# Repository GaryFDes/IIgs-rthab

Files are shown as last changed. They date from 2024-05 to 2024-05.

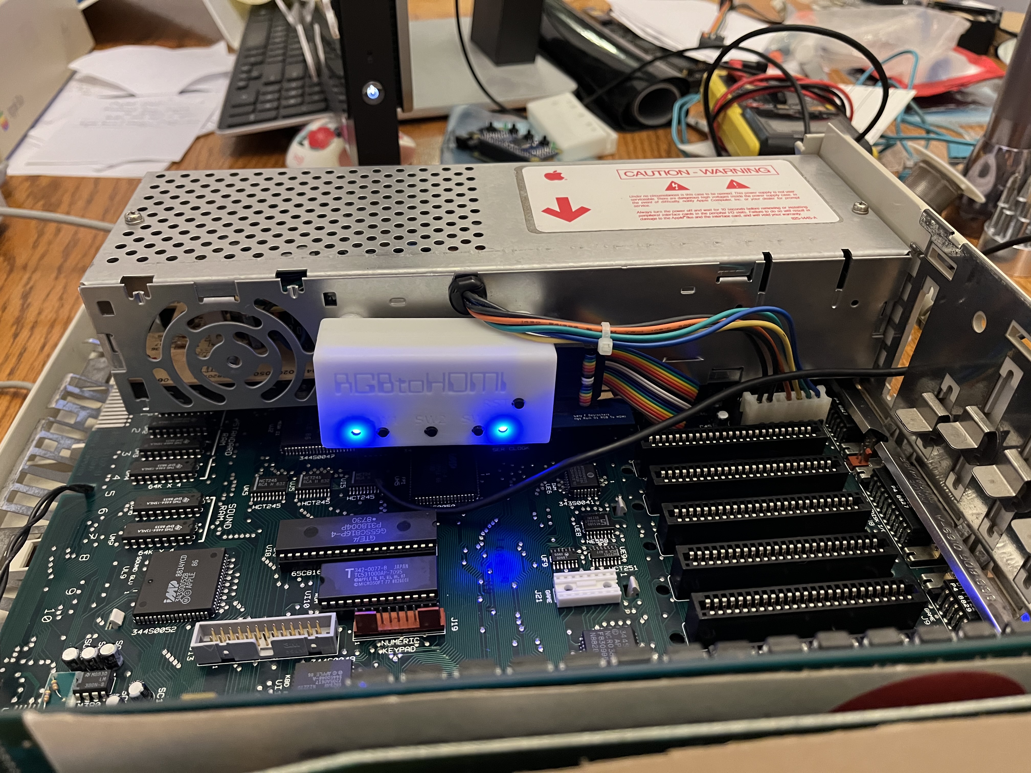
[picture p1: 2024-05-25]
pictures/Inside Setup.jpeg

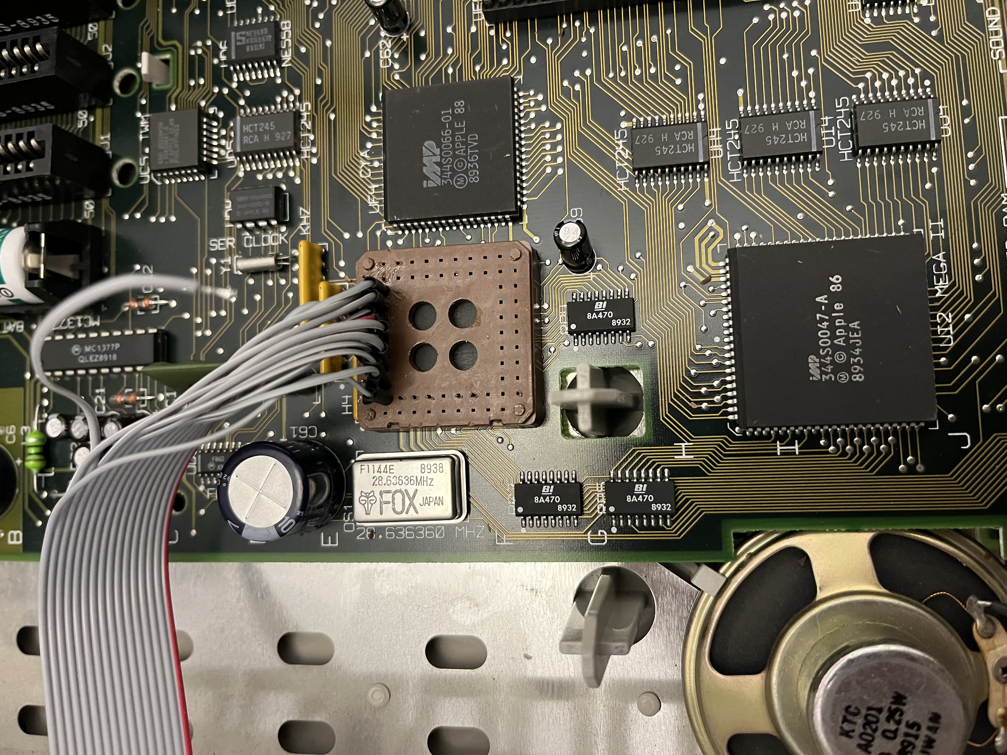
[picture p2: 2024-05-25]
pictures/ROM 03 IIgs Cap.jpeg

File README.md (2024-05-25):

# IIgs RGBToHDMI Adaptor Board
ROM 01 Apple IIgs RGBToHDMI Adapter board [Top](pictures/Top%20of%20Board.jpeg)/[Bottom](pictures/Bottom%20of%20Board.jpeg)

[Plug](https://warwickts.com/4405/W9327-68-Way-PLCC-Plug) that I used and bought there.

[Socket](https://app.adam-tech.com/products/download/data_sheet/198229/plcc-68-at-data-sheet.pdf) that I used and bought on [DigiKey](https://www.digikey.com/en/products/detail/adam-tech/PLCC-68-AT/9833042)

This is my fourth revision of this board:

* Revision 1 - The board needed the post through it (never sent this to the fab).
* Revision 2 - The traces were wired incorrectly.
* Revision 3 - The board was too big because the board had to be lower and then had to clear not only the post but the big capacitor.
* Revision 4 - This board.

I originally wanted to have the plug and socket on the bottom, and [this connection header](https://www.digikey.com/en/products/detail/te-connectivity-amp-connectors/5103308-3/1114901) on the top.  I found out in the end that I needed to solder the cable right to the header in order to have the height correct.  Also, the plug described above was too tall.  I had to cut down the plug one layer.  There is another [low height connector](https://us.warwickts.com/4391/W9305-68-Way-PLCC-Plug) that is through hole but sold only in bulk.  If I ever get enough gumption and money I will try to redesign the card with that plug in mind.

Steps are:
1) Get all the supplies (plug and PLCC68 socket).
2) Get the board(s).
3) Get (or build) an RGBToHDMI and the associated 12 bit card.
4) Cut down the plug (not an easy task).
5) Surface mount the plug.
6) Through hold solder the socket.
7) Connect the cable that is long enough to go through the opening on the IIgs.
8) Unplug the VGC (I suggest a good puller) and insert the VGC into the socket on the board. I used [this](https://www.amazon.com/dp/B00FZPSRGE)
9) Connect your RGBToHDMI 12 bit connector to the cable (!!DO NOT!! Supply power to the RGBToHDMI.  The IIgs cable already has power on it.)
10) Connect to your HDMI monitor.

I included the ROM 03 IIgs Kicad stuff because I only used a [socket](https://www.amazon.com/dp/B0C7GGJW49) over the top of the present VGC which is soldered to the motherboard. The pinout I originally did for the ROM 03 IIgs.
12) Start up the monitor and the IIgs.

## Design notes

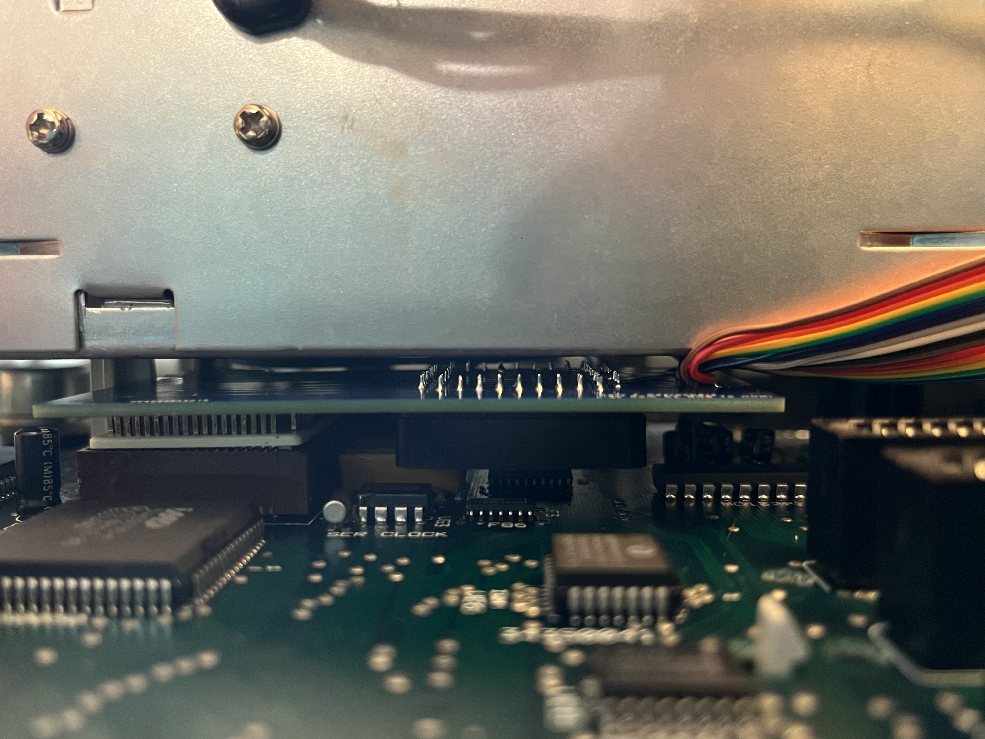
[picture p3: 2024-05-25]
pictures/Clearance Under Power Supply.jpeg

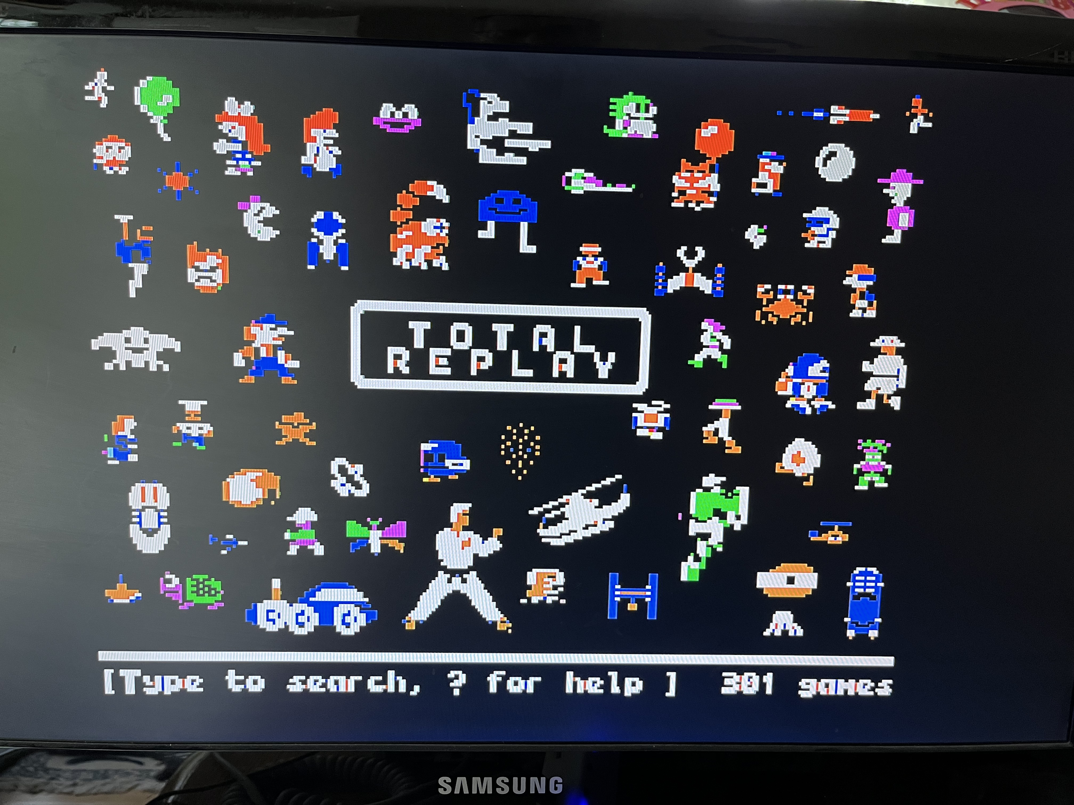
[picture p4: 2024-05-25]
pictures/Total Reply.jpeg

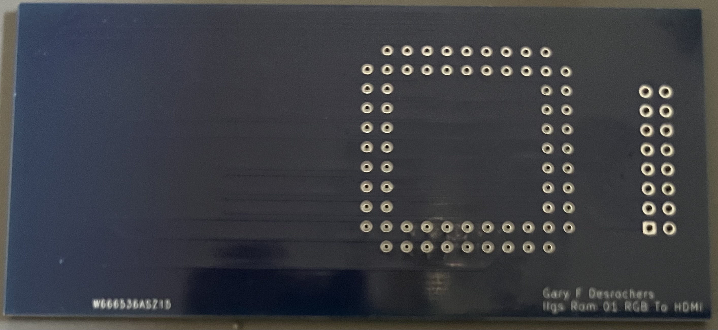
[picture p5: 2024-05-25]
pictures/Top of Board.jpeg

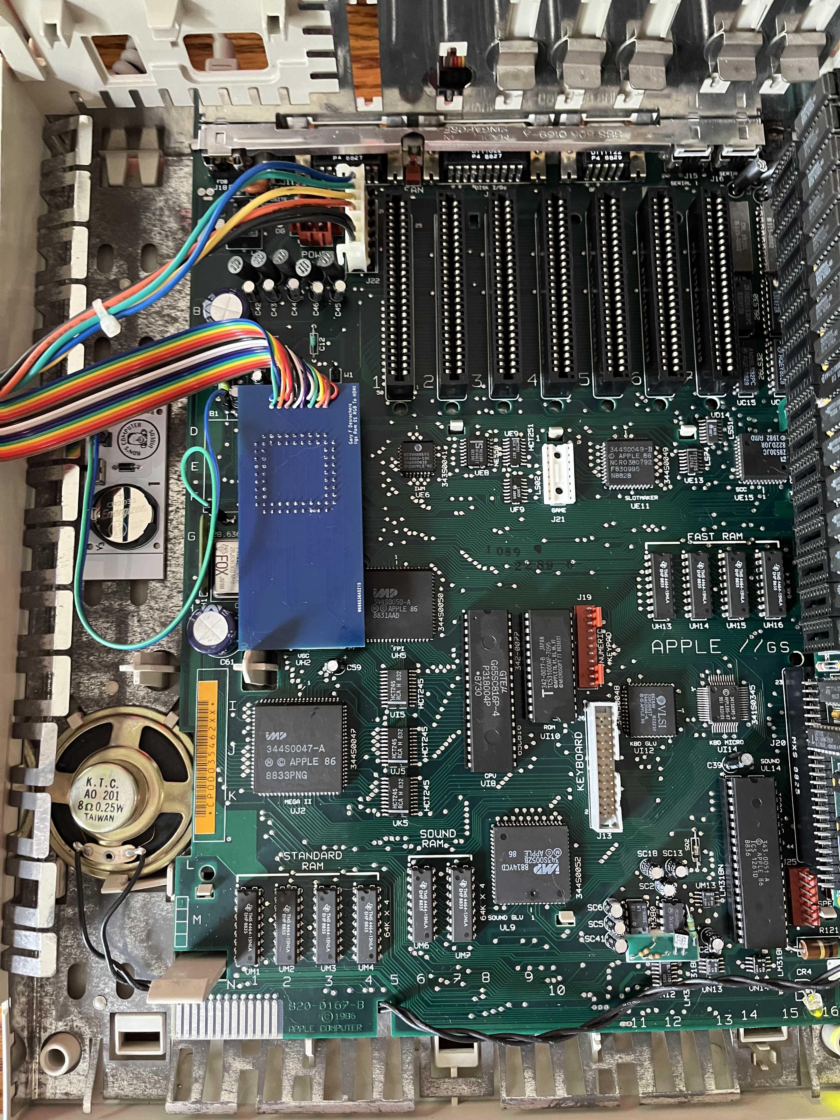
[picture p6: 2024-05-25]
pictures/Motherboard.jpeg

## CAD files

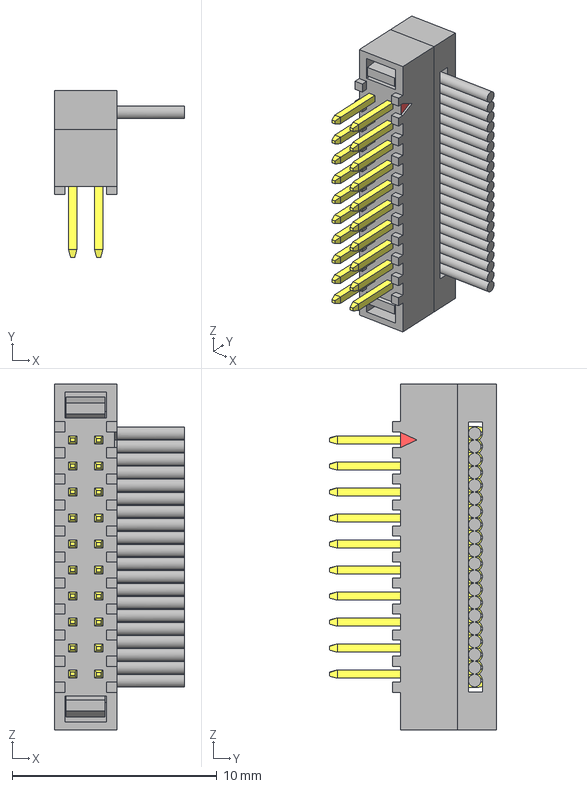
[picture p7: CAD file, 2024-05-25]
KiCad/7.0/footprints/FFMD-10-01/FFMD-10-01.step
6.35 x 8.15 x 16.9 mm
FFMD-10S_lb
FFMD-10_ub
FFMD-10_pin x 2

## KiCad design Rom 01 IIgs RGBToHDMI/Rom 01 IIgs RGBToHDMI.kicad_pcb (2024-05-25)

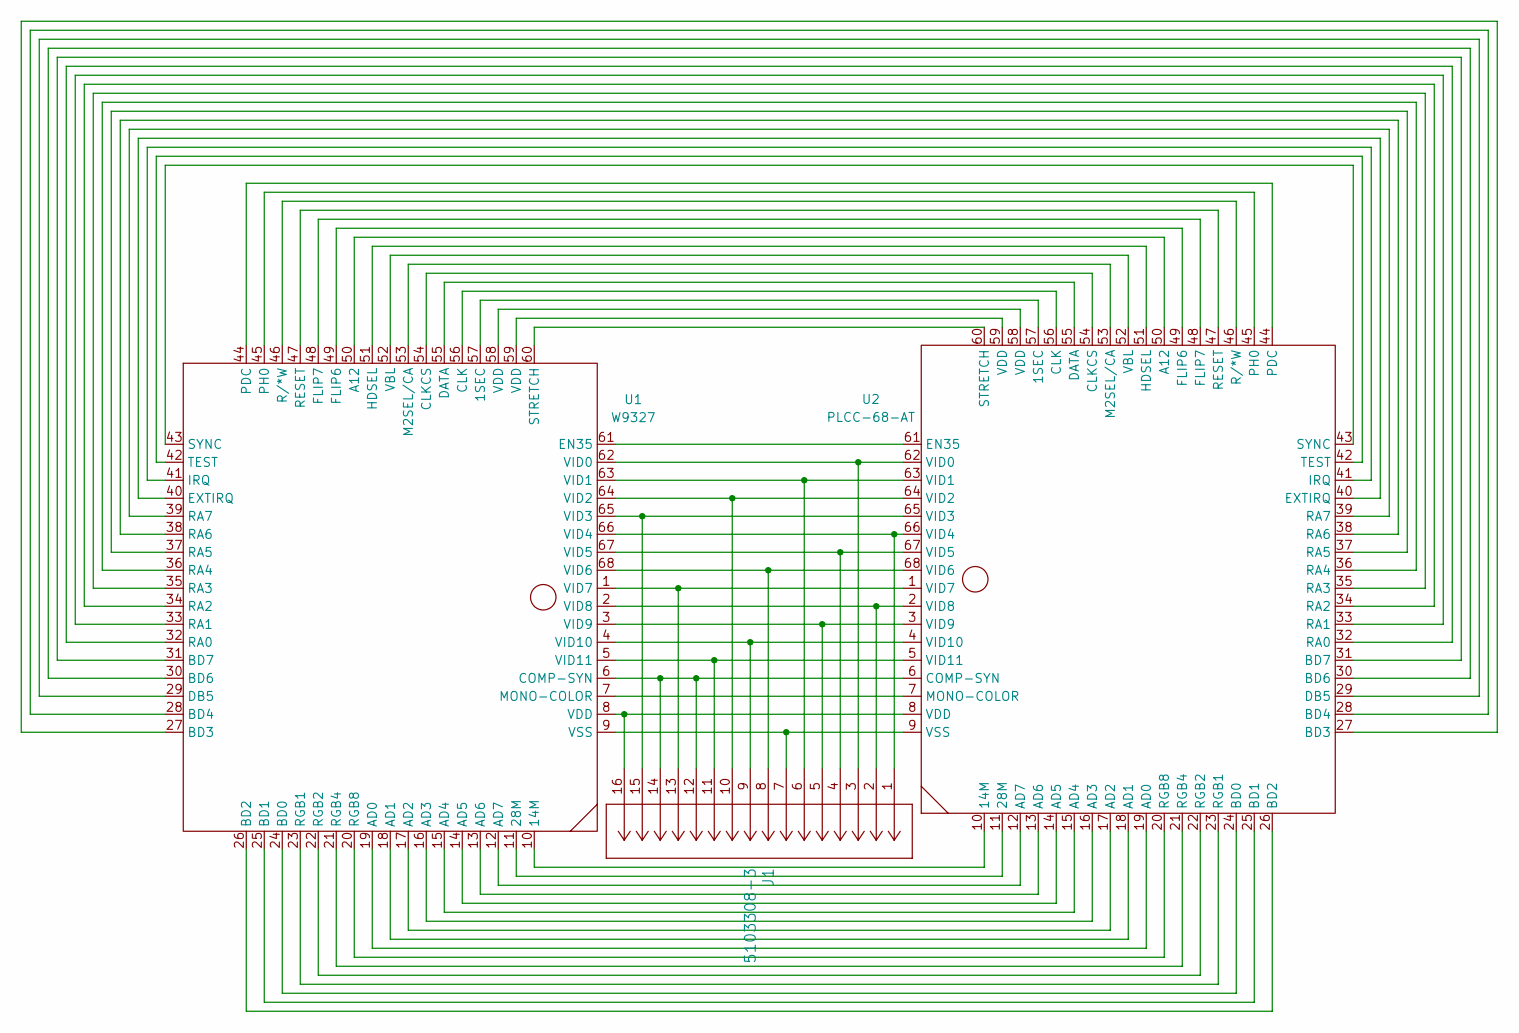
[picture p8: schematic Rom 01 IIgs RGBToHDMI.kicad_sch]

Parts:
J1: 5103308-3; con16_2X8_S4_TEC
U1: W9327; Winslow W9327
U2: PLCC-68-AT

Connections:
unnamed: J1.16, U1.8 (VDD), U2.8 (VDD)
unnamed: U1.57 (1SEC), U2.57 (1SEC)
unnamed: U1.10 (14M), U2.10 (14M)
unnamed: U1.11 (28M), U2.11 (28M)
unnamed: U1.50 (A12), U2.50 (A12)
unnamed: U1.19 (AD0), U2.19 (AD0)
unnamed: U1.18 (AD1), U2.18 (AD1)
unnamed: U1.17 (AD2), U2.17 (AD2)
unnamed: U1.16 (AD3), U2.16 (AD3)
unnamed: U1.15 (AD4), U2.15 (AD4)
unnamed: U1.14 (AD5), U2.14 (AD5)
unnamed: U1.13 (AD6), U2.13 (AD6)
unnamed: U1.12 (AD7), U2.12 (AD7)
unnamed: U1.24 (BD0), U2.24 (BD0)
unnamed: U1.25 (BD1), U2.25 (BD1)
unnamed: U1.26 (BD2), U2.26 (BD2)
unnamed: U1.27 (BD3), U2.27 (BD3)
unnamed: U1.28 (BD4), U2.28 (BD4)
unnamed: U1.30 (BD6), U2.30 (BD6)
unnamed: U1.31 (BD7), U2.31 (BD7)
unnamed: U1.56 (CLK), U2.56 (CLK)
unnamed: U1.54 (CLKCS), U2.54 (CLKCS)
unnamed: J1.12, J1.14, U1.6 (COMP-SYN), U2.6 (COMP-SYN)
unnamed: U1.55 (DATA), U2.55 (DATA)
unnamed: U1.29 (DB5), U2.29 (DB5)
unnamed: U1.61 (EN35), U2.61 (EN35)
unnamed: U1.40 (EXTIRQ), U2.40 (EXTIRQ)
unnamed: U1.49 (FLIP6), U2.49 (FLIP6)
unnamed: U1.48 (FLIP7), U2.48 (FLIP7)
unnamed: U1.51 (HDSEL), U2.51 (HDSEL)
unnamed: U1.41 (IRQ), U2.41 (IRQ)
unnamed: U1.53 (M2SEL/CA), U2.53 (M2SEL/CA)
unnamed: U1.7 (MONO-COLOR), U2.7 (MONO-COLOR)
unnamed: U1.44 (PDC), U2.44 (PDC)
unnamed: U1.45 (PH0), U2.45 (PH0)
unnamed: U1.32 (RA0), U2.32 (RA0)
unnamed: U1.33 (RA1), U2.33 (RA1)
unnamed: U1.34 (RA2), U2.34 (RA2)
unnamed: U1.35 (RA3), U2.35 (RA3)
unnamed: U1.36 (RA4), U2.36 (RA4)
unnamed: U1.37 (RA5), U2.37 (RA5)
unnamed: U1.38 (RA6), U2.38 (RA6)
unnamed: U1.39 (RA7), U2.39 (RA7)
unnamed: U1.47 (RESET), U2.47 (RESET)
unnamed: U1.23 (RGB1), U2.23 (RGB1)
unnamed: U1.22 (RGB2), U2.22 (RGB2)
unnamed: U1.21 (RGB4), U2.21 (RGB4)
unnamed: U1.20 (RGB8), U2.20 (RGB8)
unnamed: U1.46 (R/*W), U2.46 (R/*W)
unnamed: U1.60 (STRETCH), U2.60 (STRETCH)
unnamed: U1.43 (SYNC), U2.43 (SYNC)
unnamed: U1.42 (TEST), U2.42 (TEST)
unnamed: U1.52 (VBL), U2.52 (VBL)
unnamed: U1.58 (VDD), U2.58 (VDD)
unnamed: U1.59 (VDD), U2.59 (VDD)
unnamed: J1.3, U1.62 (VID0), U2.62 (VID0)
unnamed: J1.6, U1.63 (VID1), U2.63 (VID1)
unnamed: J1.10, U1.64 (VID2), U2.64 (VID2)
unnamed: J1.15, U1.65 (VID3), U2.65 (VID3)
unnamed: J1.1, U1.66 (VID4), U2.66 (VID4)
unnamed: J1.4, U1.67 (VID5), U2.67 (VID5)
unnamed: J1.8, U1.68 (VID6), U2.68 (VID6)
unnamed: J1.13, U1.1 (VID7), U2.1 (VID7)
unnamed: J1.2, U1.2 (VID8), U2.2 (VID8)
unnamed: J1.5, U1.3 (VID9), U2.3 (VID9)
unnamed: J1.9, U1.4 (VID10), U2.4 (VID10)
unnamed: J1.11, U1.5 (VID11), U2.5 (VID11)
unnamed: J1.7, U1.9 (VSS), U2.9 (VSS)

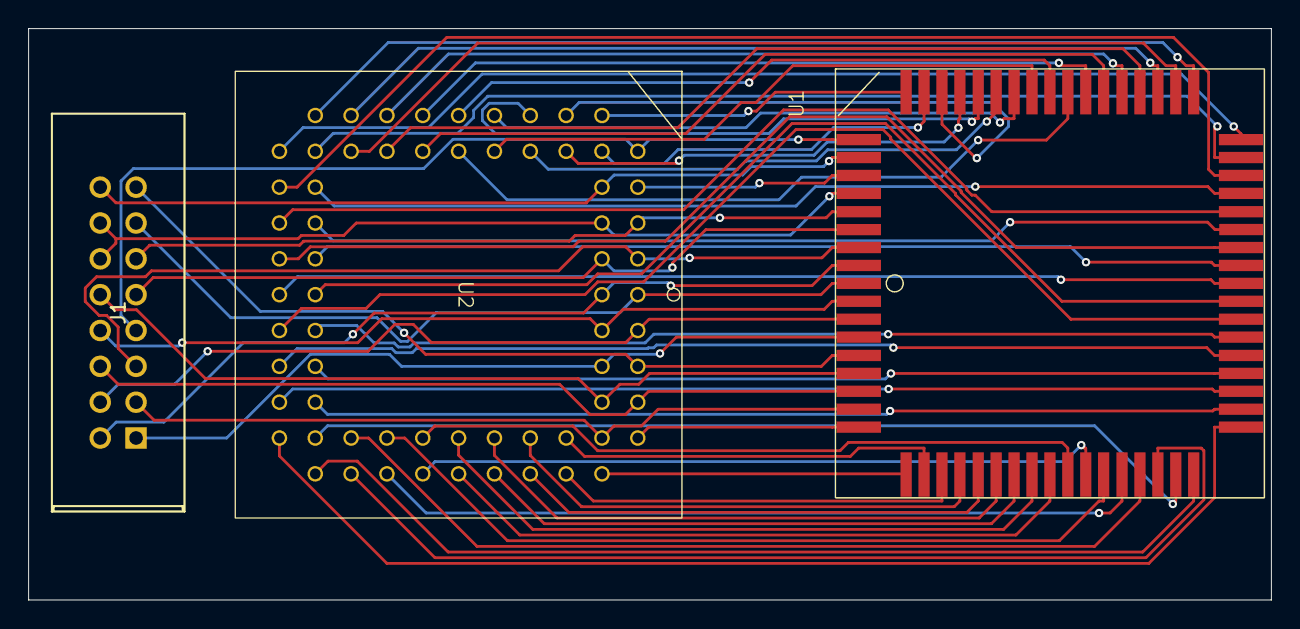
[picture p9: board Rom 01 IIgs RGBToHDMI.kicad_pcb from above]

Board: 2 copper layers, 88.1 x 40.5 mm, 3 parts (0 on the bottom side), 68 nets.

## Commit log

2024-05-25 Real first commit
    These are the files I originally have for the board I created.
    [FFMD-10-01.step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]
2024-05-25 ROM 03 IIgs Files
    Files from my Rom 03 IIgs RGBToHDMI cap I created.
    I did not produce a board for these. See the image,
    [Rom 03 IIgs RGBToHDMI.kicad_pcb, Rom 03 IIgs RGBToHDMI.kicad_sch]
2024-05-25 Board Pictures
    Just a couple of quick pictures of the board.
2024-05-25 Fix a couple of pictures
    Board pictures should not be so big and only have the board on them.

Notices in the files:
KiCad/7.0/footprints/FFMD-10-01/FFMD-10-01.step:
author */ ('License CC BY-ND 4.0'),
